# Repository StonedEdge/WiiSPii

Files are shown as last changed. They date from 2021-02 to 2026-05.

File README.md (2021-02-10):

# The Wii SPii (A custom GBA SP themed portable gaming console) 
Image of Wii SPii

## Description
The Wii SPii is an open source, portable Wii project by StonedEdge from the BitBuilt forums. It uses real Wii hardware with no emulation and lasts around 2.5 hours on a full charge. This repository includes includes code from several contributors to the hobby (Aurelio, Gmanmodz and Jefflongo), 
CAD files, gerbers for main PCB ordering and a BOM of parts for assembly. I plan to include a guide for assembly here at a later stage. The main build worklog can be found [here:](https://bitbuilt.net/forums/index.php?threads/the-wii-spii.3347/)

### Code 
The code used in this project is based on the RVL-PMS (Gman), GC+ 2.0 (Aurelio92) and STUSB4500 (jefflongo) source code from below contributors, with minor tweaks being made to suit my project needs. All credit goes to contributors and I take no credit in their work whatsoever, I simply took their contributions and made slight changes. The project code is in the form of an MPLAB X project and can be compiled using MPLAB X IDE with XC8 compiler. Alternatively, you can also use the pre-compiled program (.hex) to program the PIC16LF15324, PIC16F15324 and PIC18F25K42 with MPLAB IPE. The microcontrollers were programmed using a PICKit 3. The only code that you will need to adjust and then compile is the lines 71-74 Lmin, Lmax, Rmin and Rmax values in config.c, in order to scale the analog triggers to the correct values after reading the initial ADC values when the triggers are depressed and pressed. Code is located in the zip files. 

### CAD
The CAD files for the Wii SPii project can be found here. The case was designed with CNC manufacturing in mind and can be machined with little issue. I may include the toolpathing files at a later date, but have decided not to for now. I have uploaded both the .STEP and .STL files so that people may easily make changes to the model in their CAD software of choice, or simply print the case on any 3D printer. Prototypes were made on the Prusa i3 MK3s FDM printer and the final design was completed on a 3-axis CNC machine in acrylic plastic. I will not be taking any requests for CNC cases. 

### PCB
The PCB is a 4 layer PCB ordered from JLCPCB. The PCB can also be ordered from OSHPark or PCBway, however due to increased cost for 4-layer PCB, I would recommend ordering directly from JLCPCB for quick turnaround. A stencil is also required for ease of assembly along with solder paste and hot air to assemble the boards. I made a 3D printable stencil jig that can be used for easy placement of the stencil and PCB that I have included within the CAD zip files above. 

### BOM (Bill of Materials) 
These are the required components you will need to build the Wii SPii. This includes the PCB itself, PCB components and other peripherals required to make the console. It can be found [here:](xxx)

### Contributors 
I'd like to thank these people in no particular order for the awesome work you have done to help me complete this project. A link to their GitHub repositories can be found below. 

* Dmcke5 for helping me re-model the WiiSPii for CNC machining, CNC machining the case out of acrylic and of course the hours and hours of phone calls back and forth over the past few months. Thanks for putting up with my numerous questions on CNC
* [Gman](https://github.com/Gmanmodz) for providing the community with countless hours of research and sharing his code to allow me to make some small modifications to the LED interface and audio amplifier
* [Aurelio](https://github.com/Aurelio92) for GC+ 2.0 and BBloader Wii GUI contributions and updates
* robertlong13 for assisting in the PIC16LF15324 ADC modifications for using 10K pot for volume control over i2c
* [JeffLongo](https://github.com/jefflongo) for his STUSB4500 code revisions 
* YveltalGriffin for suggesting various hardware changes and reviews to PCB/schematics

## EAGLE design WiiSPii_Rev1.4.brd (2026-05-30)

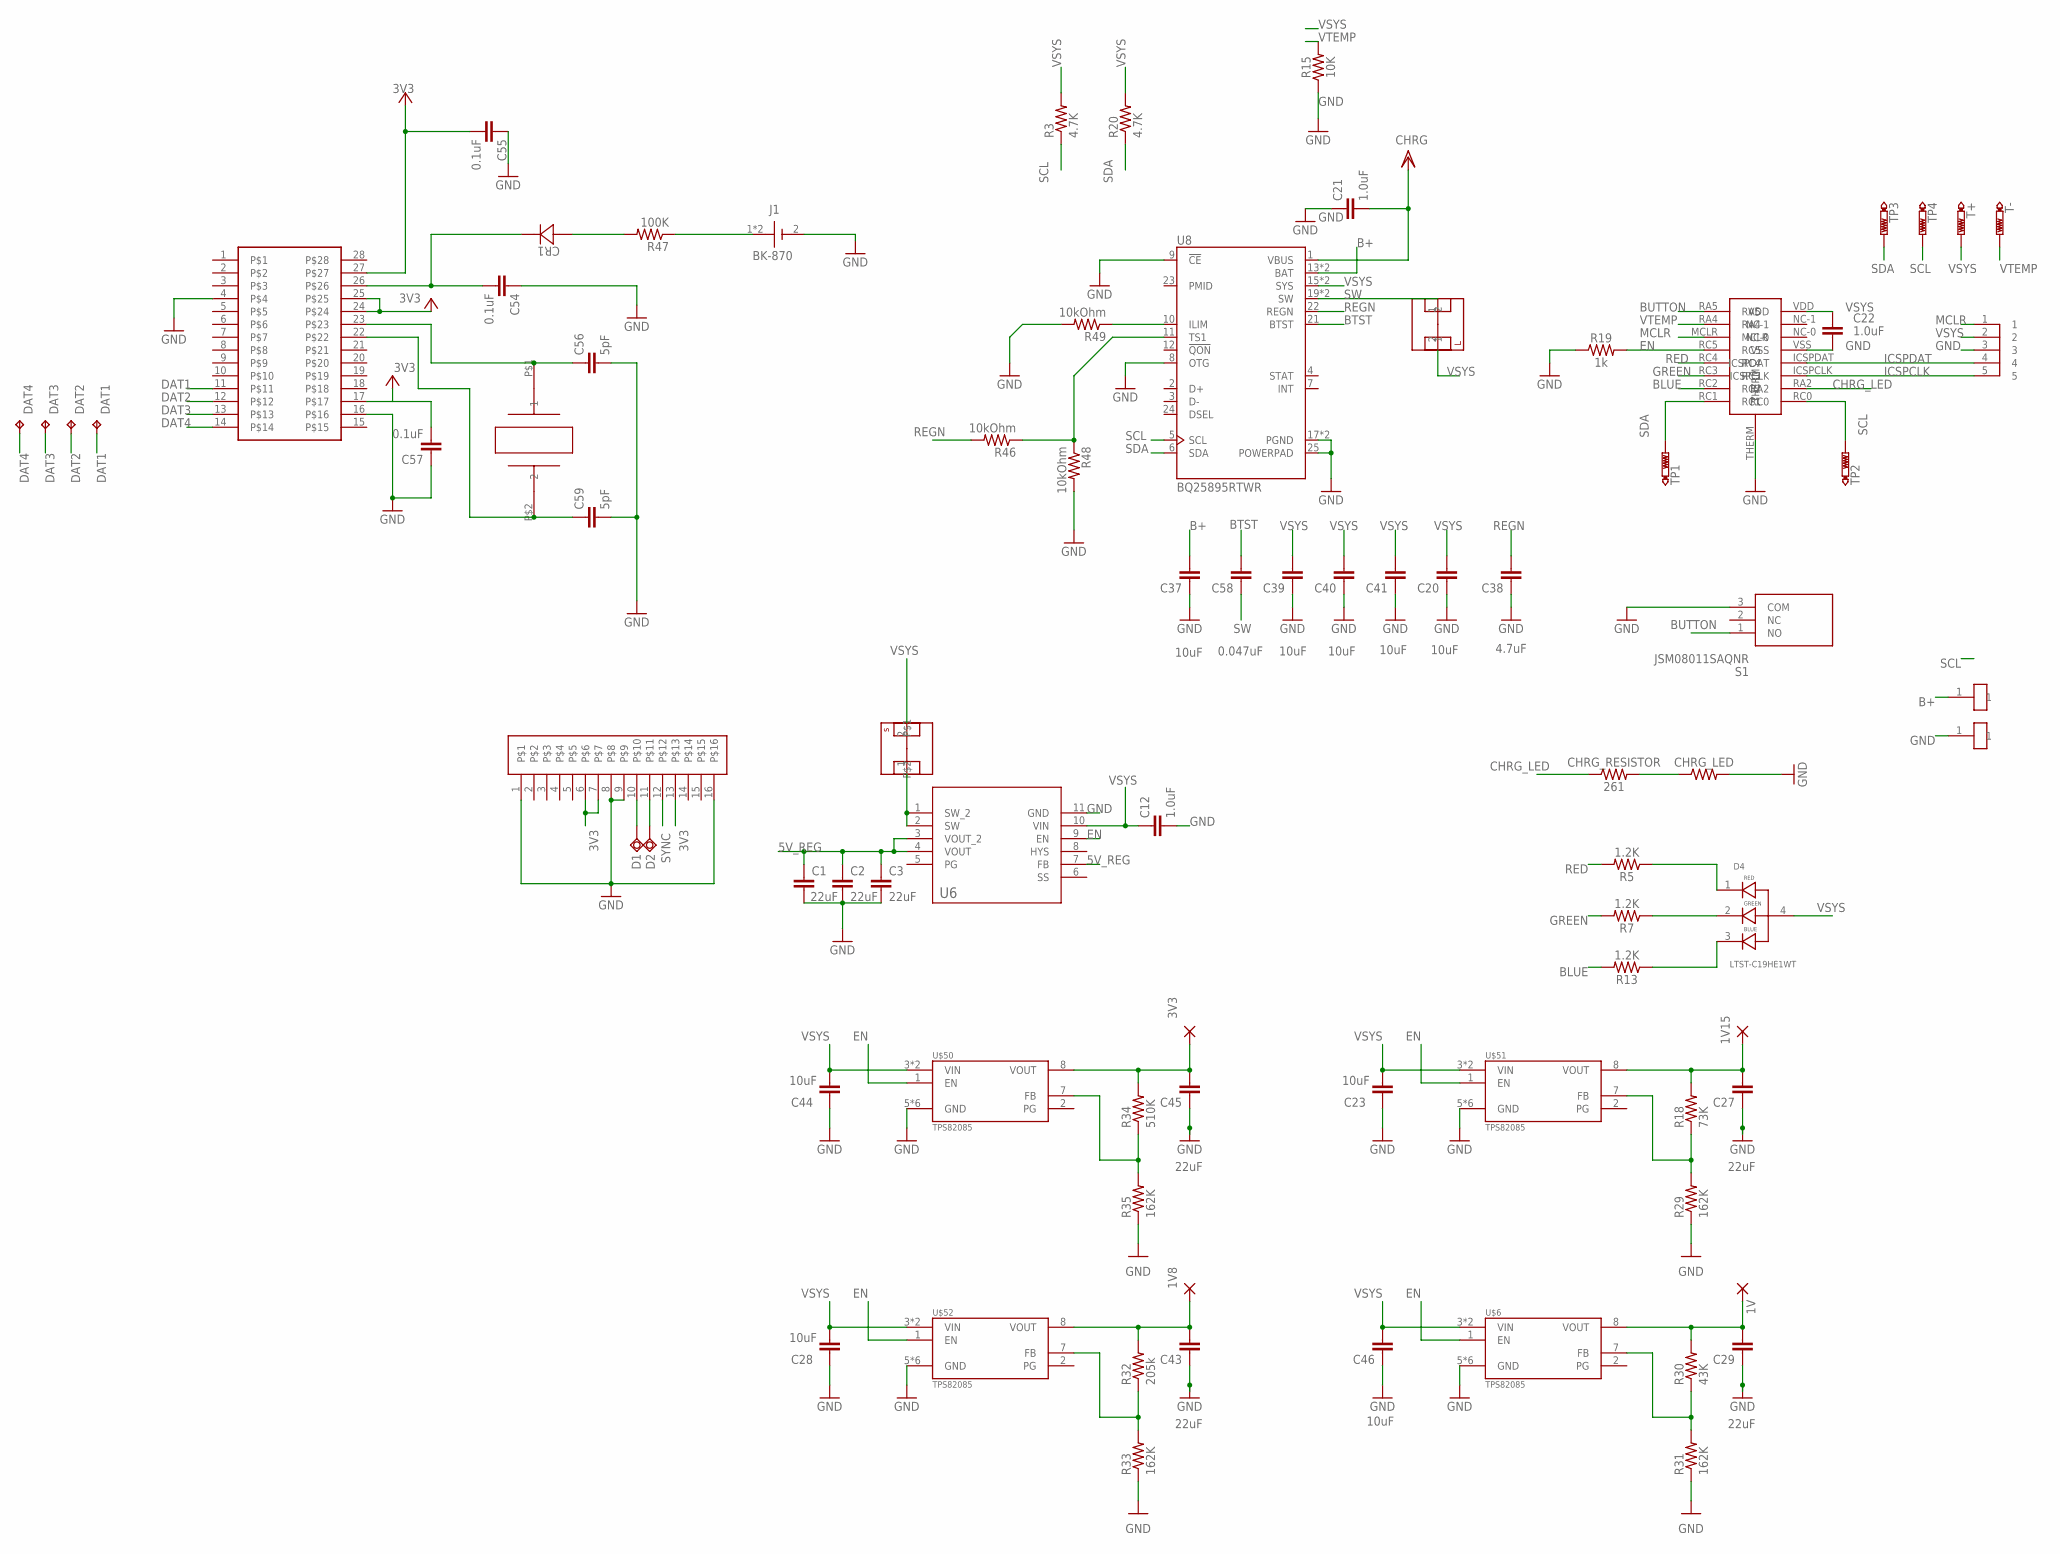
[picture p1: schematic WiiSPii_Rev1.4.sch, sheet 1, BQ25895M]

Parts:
1V, 1V8, 1V15, 3V3: SMD2; SMD1,27-2,54
BT_DATA1, BT_DATA2: TPSQB1,27; B1,27
C1, C2, C3, C27, C29, C43, C45: 22uF; 0805
C12, C21, C22: 1.0uF; 0805
C20, C23, C28, C37, C39, C40, C41, C44, C46: 10uF; 0805
C38: 4.7uF; C0402
C54, C55, C57: 0.1uF; C0402
C56, C59: 5pF; C0402
C58: 0.047uF; C0402
CHRG_LED: 261; 0603
CHRG_RESISTOR: 261; 0603
CR1: BAT60JFILM; SOD-323_STM
D4: LTST-C19HE1WT; LED_LTST-C19HE1WT
DAT1, DAT2, DAT3, DAT4: TPB1,27; B1,27
J1: BK-870; MPD_BK-870
R3, R20: 4.7K; R0402
R5, R7, R13: 1.2K; 0603
R15: 10K; 0603
R18: 73K; R0402
R19: 1k; 0603
R29, R31, R33, R35: 162K; R0402
R30: 43K; R0402
R32: 205k; R0402
R34: 510K; R0402
R46, R48, R49: 10kOhm; R0402
R47: 100K; R0402
S1: JSM08011SAQNR
T+: PTR1TP09R; TP09R
T-: PTR1TP09R; TP09R
TP1, TP2, TP3, TP4: PTR1TP09R; TP09R
U6: TPS61232DRCR; DRC_S-PVSON-N10
U8: BQ25895RTWR; VQFN50P400X400X100-24N
U$2: INDUCTOR_SMALL
U$6, U$50, U$51, U$52: TPS82085; SON65P280X300X133-9N
U$7: AUDIO_AMP_PIC
U$8: 1MM_PIC_PROGRAMING_HEADER; 1MM_PIC-PROGRAMING_HEADER
U$13: MOLEX_0541020164MOLEX
U$14: MX_WII
U$15: TFE20
U$27, U$28: VOLTAGE_PAD
U$49: INDUCTOR_LARGE; INDUCTOR_BIG

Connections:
1V: 1V.1, C29.2, R30.2, U$6.8 (VOUT)
1V8: 1V8.1, C43.2, R32.2, U$52.8 (VOUT); also elsewhere on the board
1V15: 1V15.1, C27.2, R18.2, U$51.8 (VOUT)
B+: C37.2, U8.13 (BAT), U8.14 (BAT), U$28.1
BLUE: R13.2, U$7.RC2
BTST: C58.2, U8.21 (BTST)
BUTTON: S1.1 (NO), U$7.RA5
CHRG: C21.2, U8.1 (VBUS); also elsewhere on the board
CHRG_LED: CHRG_RESISTOR.1, U$7.RA2
D1: BT_DATA1.TP, U$13.10
D2: BT_DATA2.TP, U$13.11
DAT1: DAT1.TP, U$14.11
DAT2: DAT2.TP, U$14.12
DAT3: DAT3.TP, U$14.13
DAT4: DAT4.TP, U$14.14
EN: R19.2, U6.9 (EN), U$6.1 (EN), U$7.RC5, U$50.1 (EN), U$51.1 (EN), U$52.1 (EN)
GND: C1.2, C2.2, C3.2, C12.2, C20.1, C21.1, C22.2, C23.1, C27.1, C28.1, C29.1, C37.1, C38.1, C39.1, C40.1, C41.1, C43.1, C44.1, C45.1, C46.1, C54.1, C55.1, C56.2, C57.1, C59.2, CHRG_LED.2, J1.2 (M), R15.1, R19.1, R29.1, R31.1, R33.1, R35.1, R48.2, R49.2, S1.3 (COM), U6.11 (GND), U8.8 (OTG), U8.9 (!CE), U8.17 (PGND), U8.18 (PGND), U8.25 (POWERPAD), U$6.5 (GND), U$6.6 (GND), U$6.9 (GND), U$6.P$1 (GND), U$6.P$2 (GND), U$6.P$3 (GND), U$7.THERM, U$7.VSS, U$8.3, U$13.1, U$13.8, U$13.9, U$13.16, U$14.4, U$14.16, U$27.1, U$50.5 (GND), U$50.6 (GND), U$50.9 (GND), U$50.P$1 (GND), U$50.P$2 (GND), U$50.P$3 (GND), U$51.5 (GND), U$51.6 (GND), U$51.9 (GND), U$51.P$1 (GND), U$51.P$2 (GND), U$51.P$3 (GND), U$52.5 (GND), U$52.6 (GND), U$52.9 (GND), U$52.P$1 (GND), U$52.P$2 (GND), U$52.P$3 (GND); also elsewhere on the board
GREEN: R7.2, U$7.RC3
ICSPCLK: U$7.ICSPCLK, U$8.5
ICSPDAT: U$7.ICSPDAT, U$8.4
MCLR: U$7.MCLR, U$8.1
unnamed: U6.1 (SW_2), U6.2 (SW), U$2.1
unnamed: D4.2, R7.1
unnamed: D4.1, R5.1
unnamed: D4.3, R13.1
unnamed: CHRG_LED.1, CHRG_RESISTOR.2
unnamed: C56.1, U$14.23, U$15.P$1 (1)
unnamed: C59.1, U$14.22, U$15.P$2 (2)
unnamed: CR1.2, R47.2
unnamed: R18.1, R29.2, U$51.7 (FB)
unnamed: R46.1, R48.1, U8.11 (TS1)
unnamed: R49.1, U8.10 (ILIM)
unnamed: C54.2, CR1.1, U$14.26
unnamed: J1.1, J1.3, R47.1
unnamed: R30.1, R31.2, U$6.7 (FB)
unnamed: R32.1, R33.2, U$52.7 (FB)
unnamed: R34.1, R35.2, U$50.7 (FB)
RED: R5.2, U$7.RC4
REGN: C38.2, R46.2, U8.22 (REGN)
SCL: R3.1, TP2.TP, TP4.TP, U8.5 (SCL), U$7.RC0; also elsewhere on the board
SDA: R20.1, TP1.TP, TP3.TP, U8.6 (SDA), U$7.RC1; also elsewhere on the board
SW: C58.1, U8.19 (SW), U8.20 (SW), U$49.1
SYNC: U$13.12; also elsewhere on the board
VSYS: C12.1, C20.2, C22.1, C23.2, C28.2, C39.2, C40.2, C41.2, C44.2, C46.2, D4.4, R3.2, R20.2, T+.TP, U6.10 (VIN), U8.15 (SYS), U8.16 (SYS), U$2.2, U$6.3 (VIN), U$6.4 (VIN), U$7.VDD, U$8.2, U$49.2, U$50.3 (VIN), U$50.4 (VIN), U$51.3 (VIN), U$51.4 (VIN), U$52.3 (VIN), U$52.4 (VIN); also elsewhere on the board
VTEMP: R15.2, T-.TP, U$7.RA4

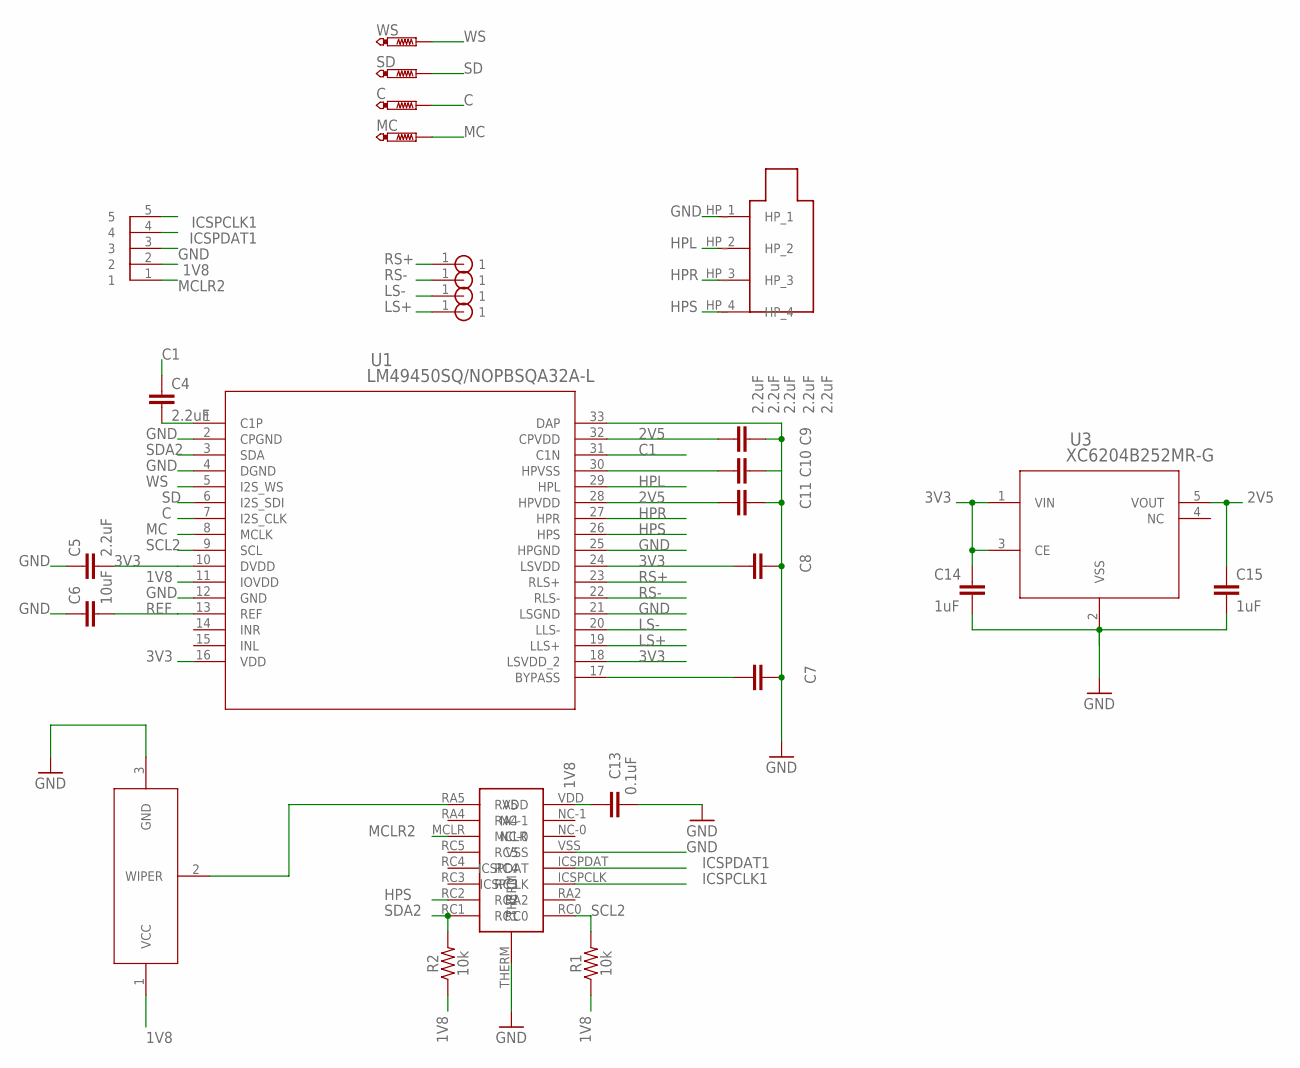
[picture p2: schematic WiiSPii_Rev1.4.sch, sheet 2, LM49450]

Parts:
C: PTR1TP09R; TP09R
C4, C5, C7, C8, C9, C10, C11: 2.2uF; 0603
C6: 10uF; 0603
C13: 0.1uF; 0603
C14, C15: 1uF; 0603
MC: PTR1TP09R; TP09R
R1, R2: 10k; 0603
RS+: WII_VIA
SD: PTR1TP09R; TP09R
U1: LM49450SQ/NOPBSQA32A-L; SQA32A-L
U3: XC6204B252MR-G; XC6204/05_SOT-25
U$1: AUDIO_AMP_PIC
U$3: 1MM_PIC_PROGRAMING_HEADER; 1MM_PIC-PROGRAMING_HEADER
U$9: RK10J11R001Y
U$40, U$41, U$42: WII_VIA
U$44: HP_JACK
WS: PTR1TP09R; TP09R

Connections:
1V8: C13.1, R1.1, R2.1, U1.11 (IOVDD), U$1.VDD, U$3.2, U$9.1 (VCC); also elsewhere on the board
2V5: C9.1, C11.1, C15.1, U1.28 (HPVDD), U1.32 (CPVDD), U3.5 (VOUT)
C: C.TP, U1.7 (I2S_CLK)
C1: C4.1, U1.31 (C1N)
GND: C5.1, C6.1, C7.1, C8.1, C9.2, C10.2, C11.2, C13.2, C14.2, C15.2, U1.2 (CPGND), U1.4 (DGND), U1.12 (GND), U1.21 (LSGND), U1.25 (HPGND), U1.33 (DAP), U3.2 (VSS), U$1.THERM, U$1.VSS, U$3.3, U$9.3 (GND), U$44.HP_1; also elsewhere on the board
HPL: U1.29 (HPL), U$44.HP_2
HPR: U1.27 (HPR), U$44.HP_3
HPS: U1.26 (HPS), U$1.RC2, U$44.HP_4
ICSPCLK1: U$1.ICSPCLK, U$3.5
ICSPDAT1: U$1.ICSPDAT, U$3.4
LS+: U1.19 (LLS+), U$42.1
LS-: U1.20 (LLS-), U$41.1
MC: MC.TP, U1.8 (MCLK)
MCLR2: U$1.MCLR, U$3.1
unnamed: C7.2, U1.17 (BYPASS)
unnamed: C10.1, U1.30 (HPVSS)
unnamed: U$1.RA5, U$9.2 (WIPER)
PIN1: C4.2, U1.1 (C1P)
REF: C6.2, U1.13 (REF)
RS+: RS+.1, U1.23 (RLS+)
RS-: U1.22 (RLS-), U$40.1
SCL2: R1.2, U1.9 (SCL), U$1.RC0
SD: SD.TP, U1.6 (I2S_SDI)
SDA2: R2.2, U1.3 (SDA), U$1.RC1
WS: U1.5 (I2S_WS), WS.TP

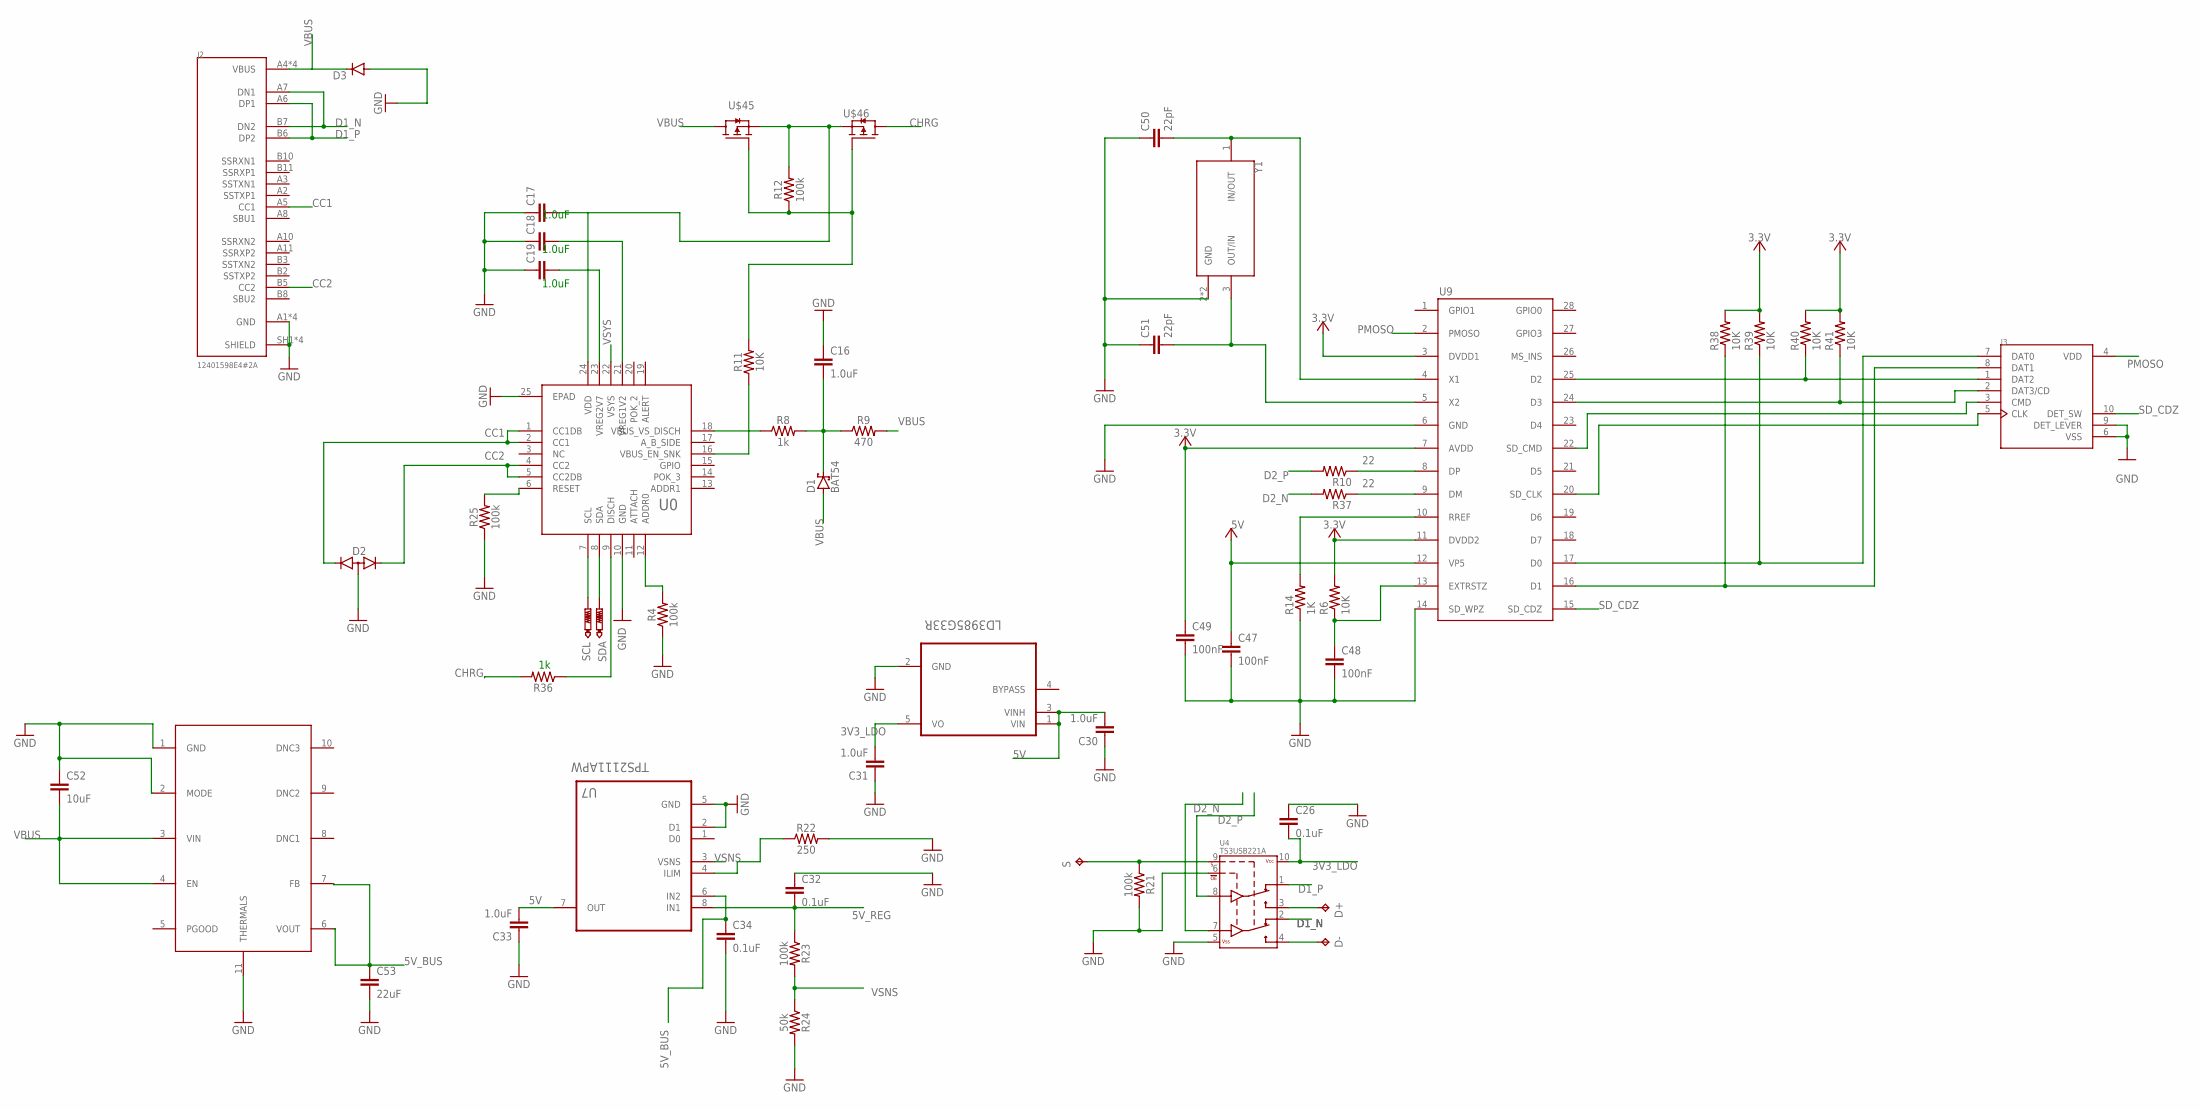
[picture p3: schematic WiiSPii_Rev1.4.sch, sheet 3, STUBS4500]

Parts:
C16, C17, C18, C19, C30, C31, C33: 1.0uF; 0603
C26, C32, C34: 0.1uF; 0603
C47, C48, C49: 100nF; C0402
C50, C51: 22pF; C0402
C52: 10uF; 1210
C53: 22uF; 1210
D1: BAT54; SOT23
D2: ESDA25W; SOT65P210X110-3N
D3: ESDA25P35-1U1M; ESDA8P801U1M
D+: TPB1,27; B1,27
D-: TPB1,27; B1,27
J2: 12401598E4#2A; AMPHENOL_12401598E4#2A
J3: 5025700893; MOLEX_5025700893
R4, R12, R21, R23, R25: 100k; 0603
R6, R38, R39, R40, R41: 10K; R0402
R8: 1k; 0603
R9: 470; 0603
R10, R37: 22; R0402
R11: 10K; 0603
R14: 1K; R0402
R22: 250; 0603
R24: 50k; 0603
R36: 1K; 0603
S: TPB1,27; B1,27
SCL: PTR1TP09R; TP09R
SDA: PTR1TP09R; TP09R
U0: STUSB4500; QFN50P440X440X100-25T255
U4: TS3USB221A; QFN-10-RSE
U5: LD3985G33R; SOT95P280X145-5N
U7: TPS2111APW; SOP65P640X120-8N
U9: GL82L_SSOP; GL827L_SSOP
U$10: LMZM23601; MODULE_LMZM23600SILR
U$45, U$46: STL6P3LLH6; POWERFLAT_3.3X3.3
Y1: ECS-120-13-30B-AEM-TR; XTAL_ECS-120-13-30B-AEM-TR

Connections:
3.3V: C49.1, R6.2, R38.2, R39.2, R40.2, R41.2, U9.3 (DVDD1), U9.7 (AVDD), U9.11 (DVDD2)
3V3_LDO: C26.2, C31.2, U4.10 (VCC), U5.5 (VO)
5V: C30.2, C33.2, C47.1, U5.1 (VIN), U5.3 (VINH), U7.7 (OUT), U9.12 (VP5)
5V_BUS: C34.1, C53.1, U7.6 (IN2), U$10.6 (VOUT), U$10.7 (FB)
CC1: D2.1 (K2), J2.A5 (CC1), U0.1 (CC1DB), U0.2 (CC1)
CC2: D2.2 (K1), J2.B5 (CC2), U0.4 (CC2), U0.5 (CC2DB)
CHRG: R36.2, U$46.5 (D), U$46.6 (D), U$46.7 (D); also elsewhere on the board
D1_N: J2.A7 (DN1), J2.B7 (DN2), U4.2 (1D-)
D1_P: J2.A6 (DP1), J2.B6 (DP2), U4.1 (1D+)
D2_N: R37.2, U4.7 (D-)
D2_P: R10.2, U4.8 (D+)
GND: C16.1, C17.1, C18.1, C19.1, C26.1, C30.1, C31.1, C32.1, C33.1, C34.2, C47.2, C48.2, C49.2, C50.1, C51.1, C52.1, C53.2, D2.3 (A), D3.1 (A), J2.A1 (GND), J2.A12 (GND), J2.B1 (GND), J2.B12 (GND), J2.SH1 (SHIELD), J2.SH2 (SHIELD), J2.SH3 (SHIELD), J2.SH4 (SHIELD), J3.6 (VSS), J3.9 (DET_LEVER), R4.1, R14.1, R21.2, R22.2, R24.2, R25.1, U0.10 (GND), U0.25 (EPAD), U4.5 (VSS), U4.6 (!OE), U5.2 (GND), U7.2 (D1), U7.5 (GND), U9.6 (GND), U9.14 (SD_WPZ), U$10.1 (GND), U$10.2 (MODE), U$10.11 (THERMALS), Y1.2 (GND), Y1.4 (GND); also elsewhere on the board
unnamed: R4.2, U0.12 (ADDR0)
unnamed: R8.1, U0.18 (VBUS_VS_DISCH)
unnamed: C19.2, U0.23 (VREG2V7)
unnamed: R11.1, U0.16 (VBUS_EN_SNK)
unnamed: R11.2, R12.1, U$45.4 (G), U$46.4 (G)
unnamed: R36.1, U0.9 (DISCH)
unnamed: D-.TP, U4.4 (2D-)
unnamed: D+.TP, U4.3 (2D+)
unnamed: R22.1, U7.4 (ILIM)
unnamed: R25.2, U0.6 (RESET)
unnamed: C18.2, U0.21 (VREG1V2)
unnamed: C16.2, D1.3 (C), R8.2, R9.1
unnamed: C48.1, R6.1, U9.13 (EXTRSTZ)
unnamed: R14.2, U9.10 (RREF)
unnamed: R10.1, U9.8 (DP)
unnamed: R37.1, U9.9 (DM)
unnamed: C50.2, U9.4 (X1), Y1.1 (IN/OUT)
unnamed: J3.1 (DAT2), R40.1, U9.25 (D2)
unnamed: J3.2 (DAT3/CD), R41.1, U9.24 (D3)
unnamed: J3.3 (CMD), U9.22 (SD_CMD)
unnamed: J3.5 (CLK), U9.20 (SD_CLK)
unnamed: J3.8 (DAT1), R38.1, U9.16 (D1)
unnamed: J3.7 (DAT0), R39.1, U9.17 (D0)
unnamed: C51.2, U9.5 (X2), Y1.3 (OUT/IN)
PMOSO: J3.4 (VDD), U9.2 (PMOSO)
SCL: SCL.TP, U0.7 (SCL); also elsewhere on the board
SDA: SDA.TP, U0.8 (SDA); also elsewhere on the board
SD_CDZ: J3.10 (DET_SW), U9.15 (SD_CDZ)
VBUS: C52.2, D1.1 (A), D3.2 (C), J2.A4 (VBUS), J2.A9 (VBUS), J2.B4 (VBUS), J2.B9 (VBUS), R9.2, U$10.3 (VIN), U$10.4 (EN), U$45.5 (D), U$45.6 (D), U$45.7 (D)
VCC: C17.2, R12.2, U0.24 (VDD), U$45.1 (S), U$45.2 (S), U$45.3 (S), U$46.1 (S), U$46.2 (S), U$46.3 (S)
VSNS: R23.2, R24.1, U7.3 (VSNS)
VSYS: U0.22 (VSYS); also elsewhere on the board

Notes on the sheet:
1.0uF

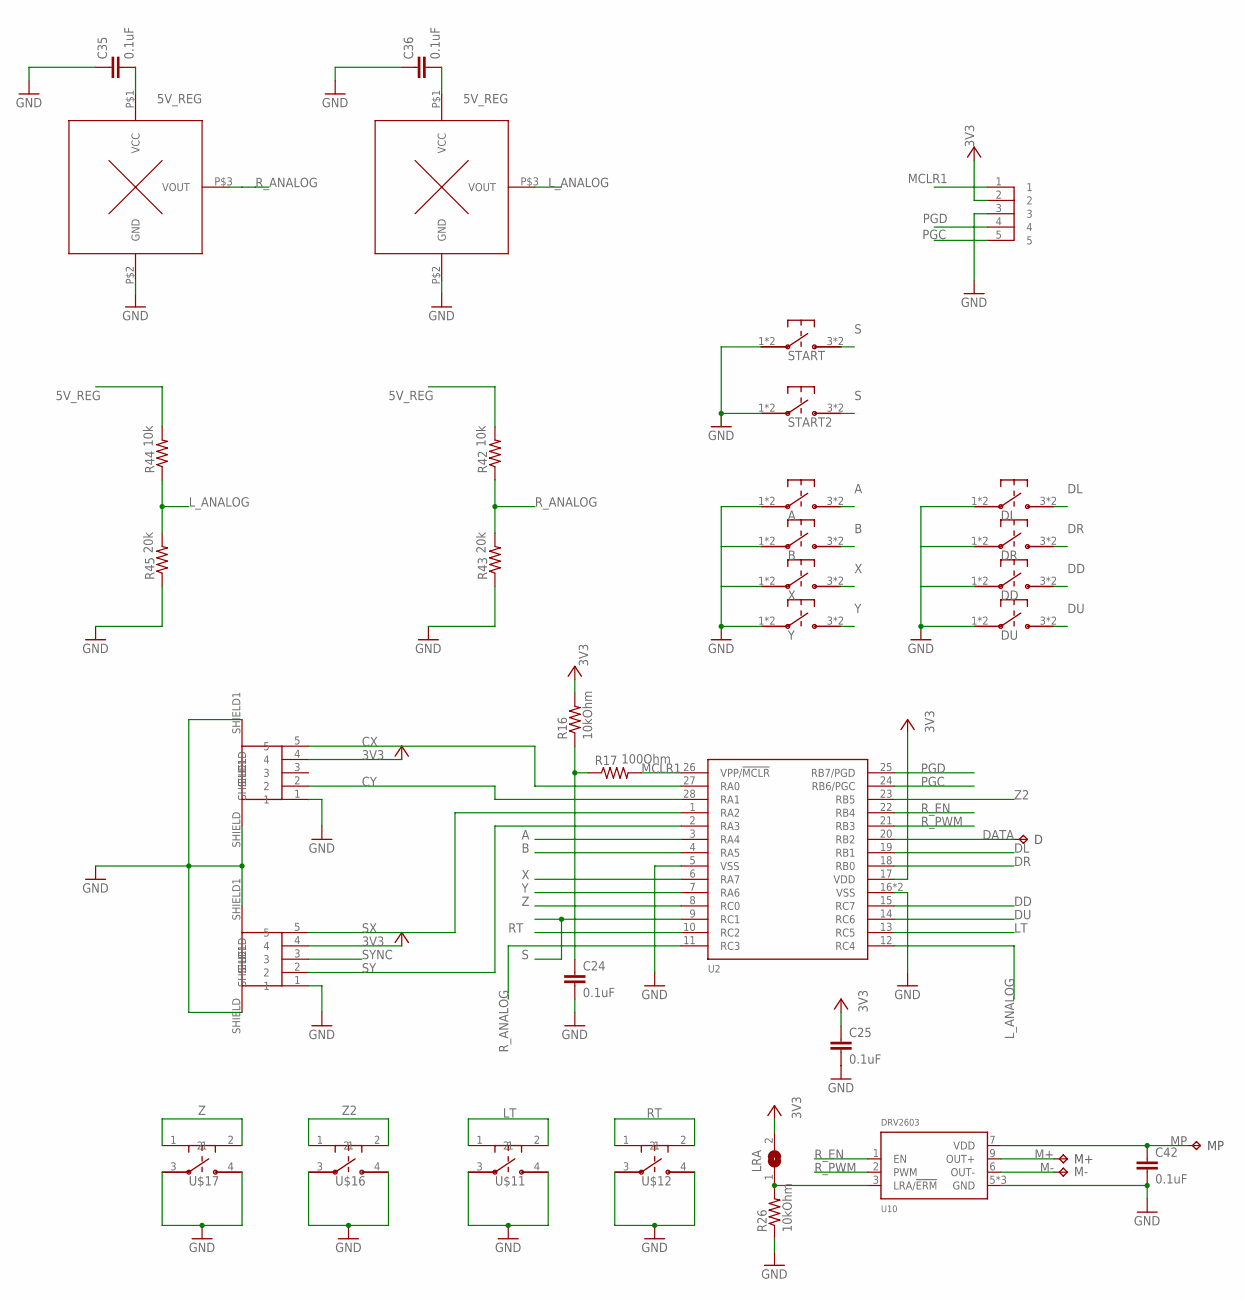
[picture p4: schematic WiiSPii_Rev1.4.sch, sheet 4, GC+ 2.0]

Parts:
A: TL3315NF100Q
B: TL3315NF100Q
C24, C25, C35, C36, C42: 0.1uF; C0402
DATA: TPTP10SQ; TP10SQ
DD: TL3315NF100Q
DL: TL3315NF100Q
DR: TL3315NF100Q
DU: TL3315NF100Q
HS1, HS2: MLX90290
LRA: SJ
M+: TPTP10SQ; TP10SQ
M-: TPTP10SQ; TP10SQ
MP: TPTP10SQ; TP10SQ
R16, R26: 10kOhm; R0402
R17: 100Ohm; R0402
R42, R44: 10k; R0402
R43, R45: 20k; R0402
START, START2: TL3315NF100Q
U2: PIC18F25K42; QFN-28
U10: DRV2603; WQFN-10
U$4, U$5: SWITCHSTICK_BREAKOUT
U$11, U$12, U$16, U$17: EVQ-P7J01P
U$18: 1MM_PIC_PROGRAMING_HEADER; 1MM_PIC-PROGRAMING_HEADER
X: TL3315NF100Q
Y: TL3315NF100Q

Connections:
A: A.3, A.4, U2.3 (RA4)
B: B.3, B.4, U2.4 (RA5)
CX: U2.27 (RA0), U$5.5
CY: U2.28 (RA1), U$5.2
DD: DD.3, DD.4, U2.15 (RC7)
DL: DL.3, DL.4, U2.19 (RB1)
DR: DR.3, DR.4, U2.18 (RB0)
DU: DU.3, DU.4, U2.14 (RC6)
GND: A.1, A.2, B.1, B.2, C24.2, C25.2, C35.1, C36.1, C42.2, DD.1, DD.2, DL.1, DL.2, DR.1, DR.2, DU.1, DU.2, HS1.P$2 (GND), HS2.P$2 (GND), R26.1, R43.1, R45.1, START.1, START.2, START2.1, START2.2, U2.5 (VSS), U2.16 (VSS), U10.5 (GND), U10.8 (GND), U10.10 (GND), U$4.1, U$4.SHIELD, U$4.SHIELD1, U$5.1, U$5.SHIELD, U$5.SHIELD1, U$11.3, U$11.4, U$12.3, U$12.4, U$16.3, U$16.4, U$17.3, U$17.4, U$18.3, X.1, X.2, Y.1, Y.2; also elsewhere on the board
LT: U2.13 (RC5), U$11.1, U$11.2
M+: M+.TP, U10.9 (OUT+)
M-: M-.TP, U10.6 (OUT-)
MCLR1: R17.2, U2.26 (VPP/!MCLR), U$18.1
MP: C42.1, MP.TP, U10.7 (VDD)
unnamed: LRA.1, R26.2, U10.3 (LRA/!ERM)
unnamed: DATA.TP, U2.20 (RB2)
unnamed: C24.1, R16.1, R17.1
PGC: U2.24 (RB6/PGC), U$18.5
PGD: U2.25 (RB7/PGD), U$18.4
RT: U2.10 (RC2), U$12.1, U$12.2
R_EN: U2.22 (RB4), U10.1 (EN)
R_PWM: U2.21 (RB3), U10.2 (PWM)
S: START.3, START.4, START2.3, START2.4, U2.9 (RC1)
SX: U2.1 (RA2), U$4.5
SY: U2.2 (RA3), U$4.2
SYNC: U$4.3; also elsewhere on the board
X: U2.6 (RA7), X.3, X.4
Y: U2.7 (RA6), Y.3, Y.4
Z: U2.8 (RC0), U$17.1, U$17.2
Z2: U2.23 (RB5), U$16.1, U$16.2

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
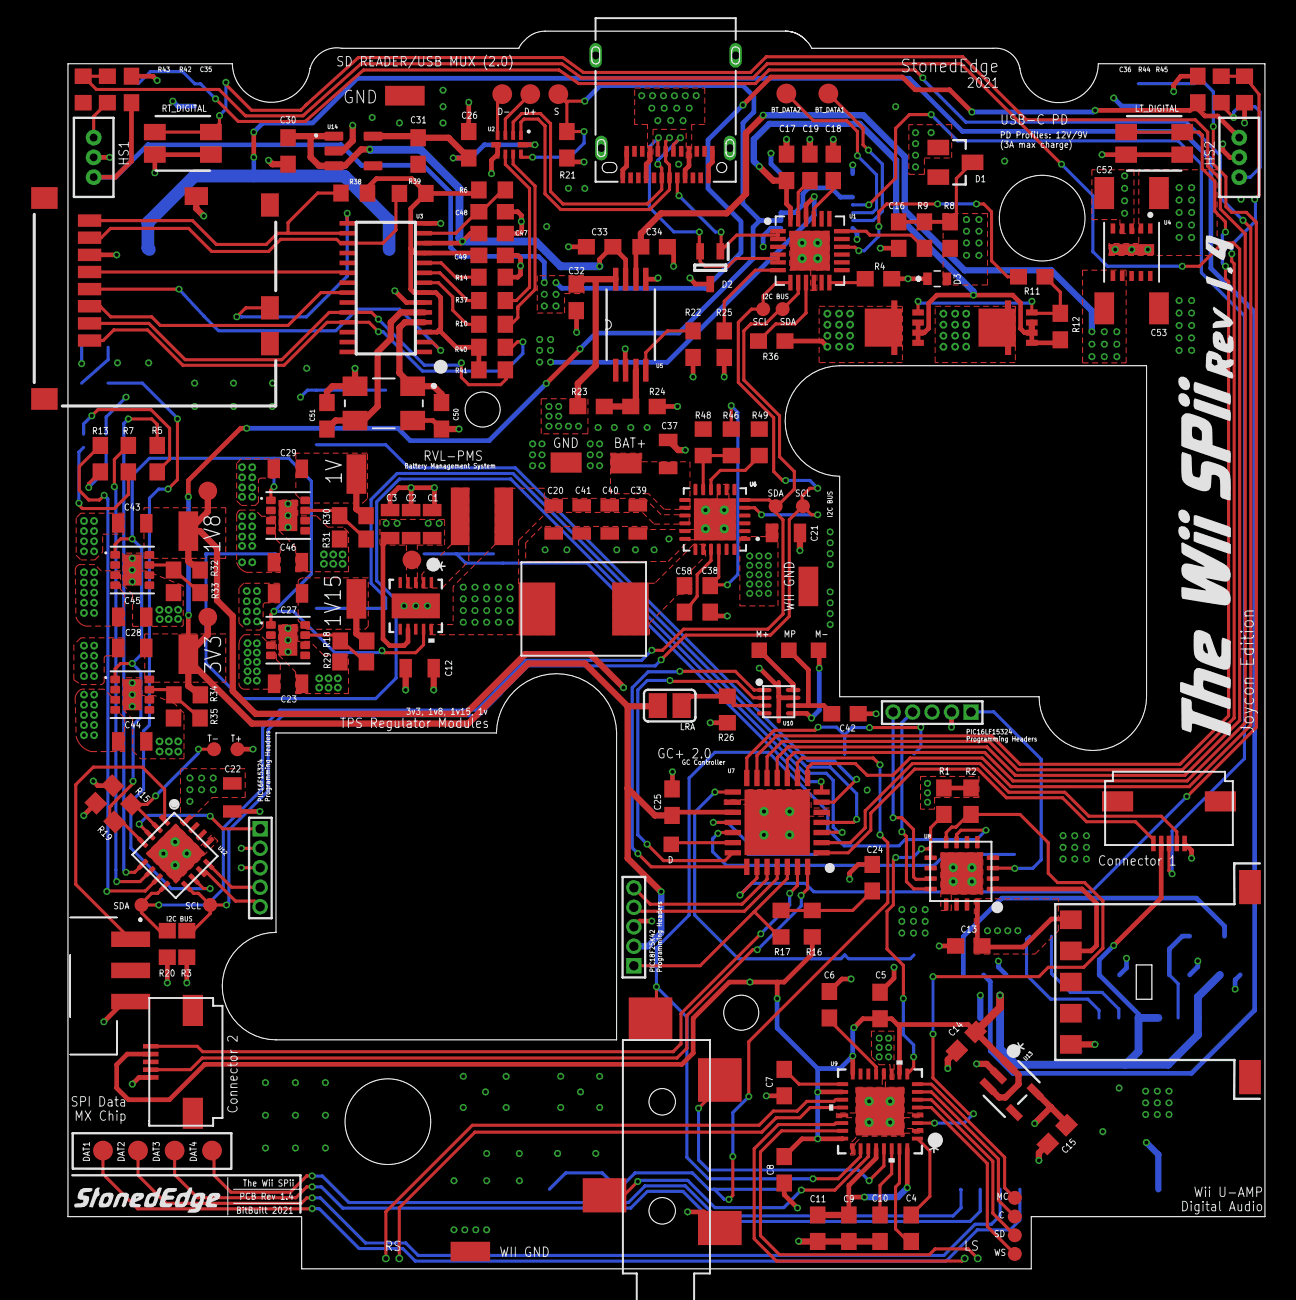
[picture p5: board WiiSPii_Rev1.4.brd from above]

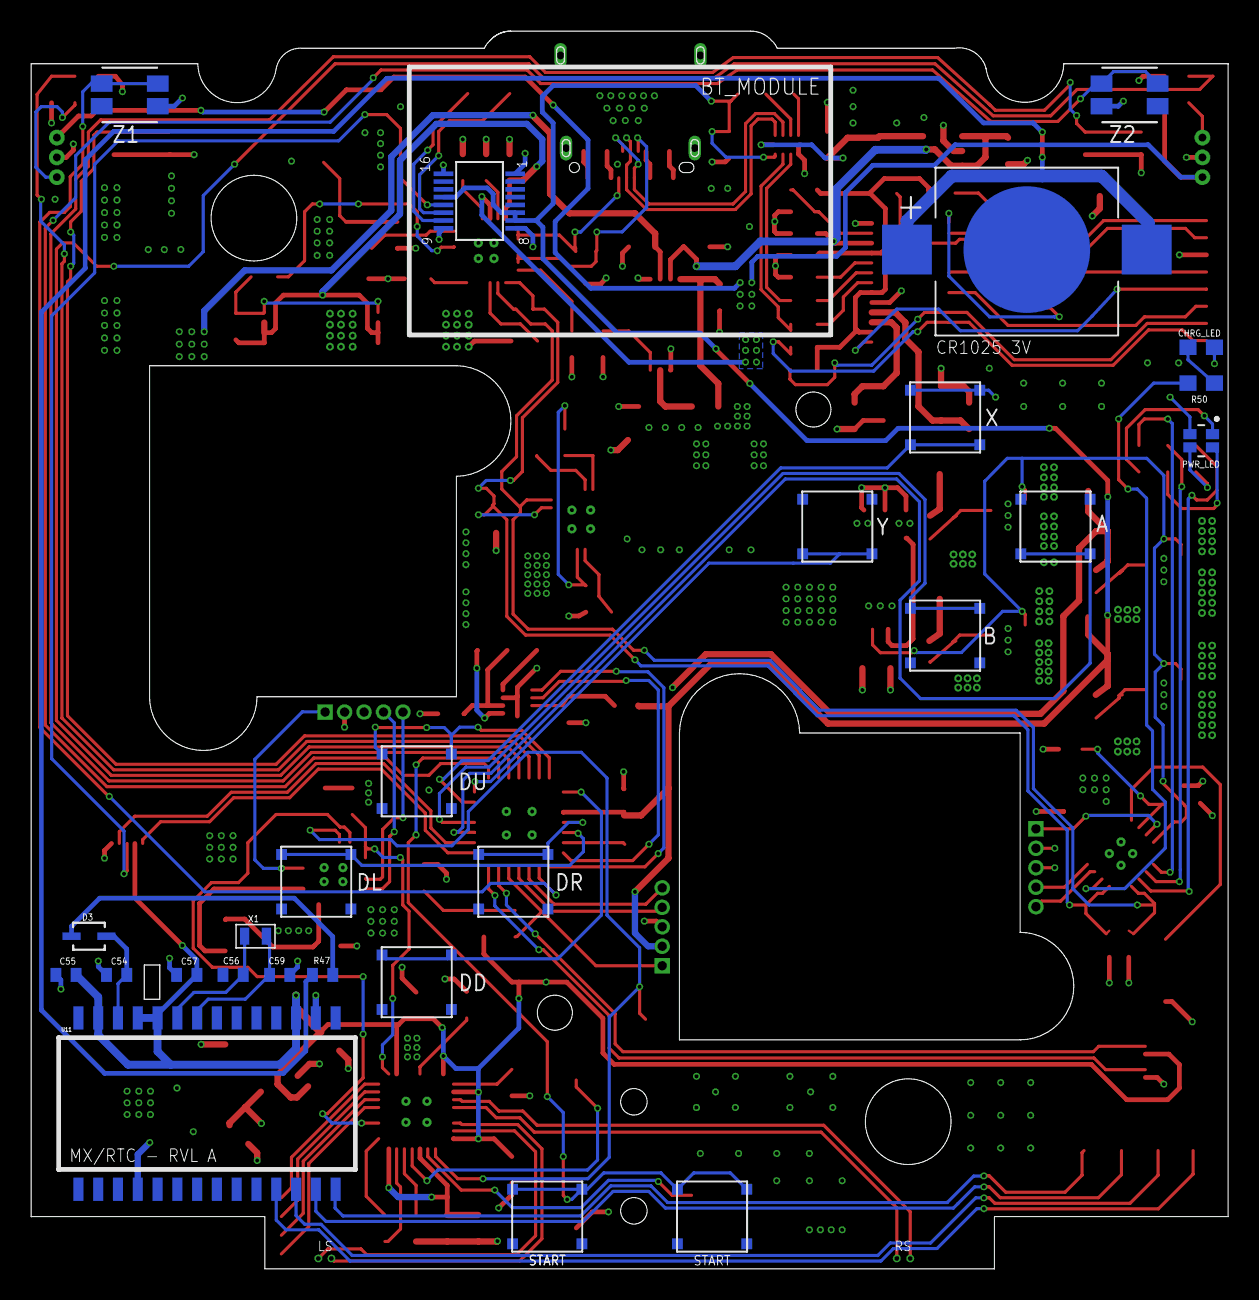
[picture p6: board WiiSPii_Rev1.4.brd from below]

Board: 4 copper layers, 76.8 x 79.4 mm, 208 parts (27 on the bottom side), 141 nets.

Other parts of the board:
3V3_SCREEN: PTR1TP12R; TP12R
GND: SMD1,27-2,54
GND(WII), GND(WII)1: SMD1,27-2,54
TP6, TP7: PTR1TP12R; TP12R

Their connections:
1V8: TP6.TP; also elsewhere on the board
GND: GND.1, GND(WII).1, GND(WII)1.1; also elsewhere on the board

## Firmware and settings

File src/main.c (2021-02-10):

#include <xc.h>
#include <stdint.h>
#include <pic16f15324.h>
#include "PICCONFIG.h"
#include "PWM.h"
#include "PPS.h"
#include "I2C.h"
#include "BQ25895M.h"
#include "ADC.h"
#include "LED_INTERFACE.h"
#include "NVM.h"
#include "stusb4500.h"
#include "stusb4500_nvm.h"
#include "time.h"

uint8_t SYS_ENABLE = 0;

void PIC_SETUP(){
    
    CPUDOZEbits.IDLEN = 0;      //clear idle mode
    VREGCON = 0b00000011;       //low power sleep mode
    
    //IO setup
    TRISA = 0b11111011; // set RA2 to output
    TRISC = 0xFF;
    ANSELA = 0;
    ANSELC = 0;
    ANSELAbits.ANSA4 = 1;   //thermistor
    WPUA = 0b00100000;      //WPU on RA5 BTN
    
    //TIMER1 setup
    T1CONbits.CKPS = 0b00;  //1:1 prescale
    T1CONbits.nSYNC = 0;
    T1CONbits.RD16 = 1;     //16-bit read
    T1GCONbits.GE = 0;      //Gate OFF
    T1CLK = 0b00000100;     //CLK is LFINTOSC
    TMR1 = TMR1_RST;  
    PIE4bits.TMR1IE = 1;    //enable tmr1 interrupt     
    T1CONbits.ON = 1;
    
    //IOC setup
    PIE0bits.IOCIE = 1;     //enable IOC module
    IOCAP = 0b00100000;     //PSEDGE enable bits
    IOCAN = 0b00100000;     //NEGEDGE enable bits
    IOCAF = 0x00;
    
    INTCONbits.GIE = 1;     //enable active interrupts
    INTCONbits.PEIE = 1;    //enable peripheral interrupts
}

uint8_t btn_is_pressed = 0;
uint8_t btn_is_debounced = 0;
uint32_t btn_time_start = 0;
uint32_t btn_time = 0;

void interrupt ISR(){

    if(TMR1IF) {
        TMR1IF = 0;
        TMR1 = TMR1_RST;
        timer_counter++;
    }
    
    if(IOCAF5) {
        IOCAF5 = 0;
    }
    
    if(!pwr_btn) {
        if(!btn_is_pressed) {
            btn_time_start = get_time();
        }
        btn_is_pressed = 1;
    } 
    else {
        if(btn_is_pressed) {
            btn_time = timer_diff(btn_time_start);
            if(btn_time >= 5) {
                btn_is_debounced = 1;
            }
        }
        btn_is_pressed = 0;
    }
    
} 

void thermal_protection(){    
    //calculating setpoint = 255 / [(Therm_resistance(at temp) / 10,000 ) + 1]
    //For temp = 75C, setpoint = 222
    if(readADC(ADCRA4) >= 222) {
        SYS_ENABLE = 0;
        TRISCbits.TRISC5 = 1;       //turn off regulators
        BQ_Write(0x09, 0b01100100); //Force BATFET off 
    }    
}

uint8_t set_stusb4500 = 0;
uint32_t stusb4500_timeout = 0;

void main() {
            
    PIC_SETUP();
    
    //clear i2c bus if SDA held low
    I2C_bus_reset();
    
    //Initialize I2C Master
    PPS_unlock();
    SSP1DATPPS = 0x11;  //SDA INPUT
    RC1PPS = 0x16;      //SDA OUTPUT
    SSP1CLKPPS = 0x10;  //SDA INPUT
    RC0PPS = 0x15;      //SCL OUTPUT
    PPS_lock();
    I2C_Master_Init(350000);   
    
    BQ_CONFIG_INIT();
    BQ_INIT();
    
    PWM_INIT();

    while(1) {
        
        CLRWDT();
        
        if(btn_is_debounced) {
            if(btn_time >= 85) {                   //btn is long press
                SYS_ENABLE = !SYS_ENABLE;
                if(SYS_ENABLE) {
                    TRISCbits.TRISC5 = 0;
                    enable = 1;                     //turn on regulators   
                    nvm_flash();
                    //ps2_on();
                }
                else {
                    TRISCbits.TRISC5 = 1;           //turn off regulators
                }
            }
            else if(SYS_ENABLE && btn_time<=50 && !VBUS_CHRG_STATE[1]) {    //btn is short press
                //if battery is low, revert to mode 2 to warn user
                //.02V/bit, 2.304V offset. bit value = [(desired cutoff voltage) - 2.304] / .02V/bit
                if(BATTERY_VOLTAGE <= 50) {     //45 = (3.2 - 2.304)/.02
                    mode = 2;
                }  
            }
            btn_is_debounced = 0;
        }
        
        BQ_UPDATE();

        thermal_protection();
        
        //setting the led interface
        
if(SYS_ENABLE) {
    battery_fade();
}
else {
    led_off();
}

chrg_led();

if(VBUS_CHRG_STATE[1] == 0) {
    if(timer_diff(stusb4500_timeout) >= 500) {
        set_stusb4500 = 0;
    }
}
else {
    if(!set_stusb4500) {
        stusb_negotiate();
        set_stusb4500 = 1;
        stusb4500_timeout = get_time();           
    }
}
       
        //power consumption putting pic to sleep
        if(!SYS_ENABLE && VBUS_CHRG_STATE[1]==0 && !btn_is_debounced && pwr_btn && BQ_adc_state==0 && !set_stusb4500) {
            PWM_power_down();
            CLRWDT();
            SLEEP();    
            RESET();
        }
    }  
}

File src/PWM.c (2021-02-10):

#include <xc.h>
#include "PPS.h"

void PWM_INIT() {
    
    PPS_unlock();
    RC2PPS = 0x0B; //PWM3
    RC3PPS = 0x0C; //PWM4
    RC4PPS = 0x0D; //PWM5
    PPS_lock();

    PWM3CON = 0;
    PR2 = 255;
    PWM3DCH = 0;
    PWM3DCL = 0b00111111;
    PWM3CON = 0b10000000;
    TRISCbits.TRISC2 = 0;
    PWM3CON = 0b11110000;

    PWM4CON = 0;
    PWM4DCH = 0;
    PWM4DCL = 0b00111111;
    PWM4CON = 0b10000000;
    TRISCbits.TRISC3 = 0;
    PWM4CON = 0b11110000;

    PWM5CON = 0;
    PWM5DCH = 0;
    PWM5DCL = 0b00111111;
    PWM5CON = 0b10000000;
    TRISCbits.TRISC4 = 0;
    PWM5CON = 0b11110000;        
    
    //TIMER2 setup
    T2CLKCON = 0b00000011;  //CLK is HFINTOSC     
    TMR2ON = 1;             //TMR2 ON
    T2CKPS0 = 0;            //prescaler=16
    T2CKPS1 = 0;
    T2CKPS2 = 1;
        
    T2OUTPS0 = 1;           //postscaler=16
    T2OUTPS1 = 1;
    T2OUTPS2 = 1;
    T2OUTPS3 = 1;
        
    TMR2 = 0;               //set to 0
    PR2 = 255;              //stop value
    TMR2IF = 0;             //set flag to 0    
    
}

void PWM_power_down() {
    //shutdown pwm
    PWM3DCH = 0;
    PWM4DCH = 0;
    PWM5DCH = 0;            
    PWM3CONbits.EN = 0;
    PWM4CONbits.EN = 0;
    PWM5CONbits.EN = 0;
    
    RC2 = 1;
    RC3 = 1;
    RC4 = 1;      
    
    PPS_unlock();
    RC2PPS = 0x00; //GPIO
    RC3PPS = 0x00; //GPIO
    RC4PPS = 0x00; //GPIO
    PPS_lock();
      
}

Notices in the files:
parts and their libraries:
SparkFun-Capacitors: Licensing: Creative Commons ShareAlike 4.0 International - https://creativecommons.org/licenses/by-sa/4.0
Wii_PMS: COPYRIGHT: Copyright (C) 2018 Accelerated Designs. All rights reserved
